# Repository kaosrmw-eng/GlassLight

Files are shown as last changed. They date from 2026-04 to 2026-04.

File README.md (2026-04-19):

# GlassLight

An open-source wearable smart light designed to clip onto Meta Rayban 2 glasses. Built on the Seeed Studio XIAO ESP32-C6 with a single WS2812B LED.

  

## Features

- **7-color palette** — cycle forward/back with physical buttons
- **WiFi config portal** — hold a button 3 seconds, connect your phone, configure everything
- **Live control page** — change color and brightness from your phone over WiFi
- **Persistent notepad** — up to 2MB of notes stored in SPIFFS, survives reboots
- **Battery monitoring** — ADC voltage divider, low/critical warnings via LED
- **Auto-off timer** — configurable idle shutoff
- **Light sleep** — drops to ~3mA idle when WiFi is off
- **3D printable enclosure** — STL files coming soon

## Hardware

| Component | Details |
|---|---|
| Board | Seeed Studio XIAO ESP32-C6 |
| LED | 1× WS2812B |
| Buttons | 3× tactile (next color, prev color, toggle/config) |
| Power | LiPo battery via XIAO onboard charger |

### Pin Map

| Signal | GPIO | XIAO Label |
|---|---|---|
| WS2812B Data | 18 | D10 |
| Button — Next Color | 20 | D9 |
| Button — Prev Color | 19 | D8 |
| Button — Toggle / Config | 17 | D7 |
| Battery ADC | 0 | D0 |

### Battery Sense Wiring

A resistor voltage divider brings the LiPo voltage into ADC range:

```
BAT+ ──[ 1kΩ ]──┬── D0 (GPIO0)
                │
             [100Ω]
                │
               GND
```

Divider ratio: 100 / (1000 + 100) = 0.0909  
LiPo full ~4.2V → ADC ~474 | LiPo empty ~3.0V → ADC ~339

> **Calibration:** Open Serial Monitor at 115200 baud and send `r` to read the raw ADC value. Update `BAT_ADC_FULL` and `BAT_ADC_EMPTY` in the firmware to match your actual readings.

## Button Reference

| Button | Action |
|---|---|
| D9 (Next) | Cycle to next active color |
| D8 (Prev) | Cycle to previous active color |
| D7 (Toggle) — tap | Turn LED on / off |
| D7 (Toggle) — hold 3s | Enter WiFi config mode (3× blue blink) |

## WiFi Config Mode

Connect to `GlassLight-Setup` (open network). The captive portal opens automatically on most phones.

| URL | Page |
|---|---|
| `192.168.4.1/` | Settings (boot color, brightness, auto-off, active colors) |
| `192.168.4.1/control` | Live LED control |
| `192.168.4.1/notes` | Persistent notepad (paste, edit, copy, clear) |

## Arduino Setup

### Library Required

Install via Arduino Library Manager:
- **Adafruit NeoPixel** by Adafruit

All other libraries (`WiFi`, `WebServer`, `DNSServer`, `Preferences`, `SPIFFS`) are included in the ESP32 Arduino core.

### Board Settings

| Setting | Value |
|---|---|
| Board | `XIAO_ESP32C6` (Tools → Board → ESP32 Arduino) |
| Partition Scheme | `Default 4MB with spiffs` ← **required for notepad** |

## Battery Warnings

| Level | Behavior |
|---|---|
| ≤ 20% | 3 red flashes every 60 seconds |
| ≤ 10% | Continuous slow red pulse (LED taken over) |

## 3D Enclosure

STL files for the glasses-clip enclosure coming soon.
Arch.stl - Connects both Batter & Esp32 enclosures and slides on left arm of the Meta RayBan 2 glasses.
Batt_LED_BoxA - Enclosre for battery and LED 
Batt_LED_BoxB - " lower half
Ctl_BoxA - Enclosure for Esp32 and buttons/switch
Ctl_BoxB - " lower half

## License

MIT — do whatever you want with it. Attribution appreciated but not required.

## Author

Rich Washburn — [richwashburn.com](https://richwashburn.com)

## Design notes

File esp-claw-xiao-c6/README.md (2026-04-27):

# ESP-Claw — XIAO ESP32-C6 Board Port

Board support files for running [ESP-Claw](https://github.com/espressif/esp-claw) on the **Seeed Studio XIAO ESP32-C6**.

## Hardware

| Item | Detail |
|---|---|
| Chip | ESP32-C6 (dual-core RISC-V, 160MHz HP + 20MHz LP) |
| Flash | 4MB |
| PSRAM | None |
| Wi-Fi | 6 (802.11ax) |
| BLE | 5.0 |
| Protocol | Zigbee / Thread / Matter |
| LED | WS2812 RGB on GPIO8 |

## Files

| File | Purpose |
|---|---|
| `board_info.yaml` | Chip target declaration (`esp32c6`) |
| `board_peripherals.yaml` | RMT config for GPIO8 WS2812 (no DMA — C6 limitation) |
| `board_devices.yaml` | LED strip device definition |
| `setup_device.c` | Board initialization stub |
| `sdkconfig.defaults.board` | C6-specific config: no SPIRAM, 4MB flash, trimmed buffers |
| `partitions_4MB_c6.csv` | Single OTA slot partition table for 4MB flash |

## Key Differences from S3 Reference Board

- **No PSRAM** — ESP-Claw's task allocator detects this at runtime and falls back to internal SRAM automatically. No code changes needed.
- **4MB Flash** — Single OTA slot (no OTA-1). 512K SPIFFS for emote + 512K FAT for skills/scripts.
- **RMT no DMA** — C6's RMT peripheral doesn't support DMA. `with_dma: false` in peripherals config.
- **GPIO8** — XIAO C6 onboard WS2812 is on GPIO8 (vs GPIO38 on S3 DevKitC).
- **160MHz CPU** — C6 max is 160MHz vs 240MHz on S3. Adequate for agent loop + Telegram IM.

## Build Instructions

### Prerequisites
- ESP-IDF v5.5.4+
- `pip install esp-bmgr-assist`

### Steps

```bash
# Clone ESP-Claw
git clone https://github.com/espressif/esp-claw.git
cd esp-claw/application/basic_demo

# Copy this board directory into boards/
cp -r /path/to/this/folder ./boards/xiao_esp32c6

# Copy partition table
cp /path/to/partitions_4MB_c6.csv ./

# Generate board config
idf.py gen-bmgr-config -c ./boards -b xiao_esp32c6

# Set IDF target
idf.py set-target esp32c6

# Configure (set WiFi, LLM key, Telegram token)
idf.py menuconfig

# Build + flash
idf.py build
idf.py flash monitor
```

## Recommended Configuration (menuconfig)

- **LLM**: Claude 3.5 Sonnet or DeepSeek V3 (strong tool-use, lower token cost)
- **IM**: Telegram (lightest, most reliable on constrained hardware)
- **Disable**: QQ, Feishu, WeChat (save RAM)
- **Memory module**: Optional — disable if RAM is tight
- **Web search**: Optional — enable if you have a Brave/Tavily key

## Status

- [ ] Build verified
- [ ] Flash verified  
- [ ] Telegram IM working
- [ ] Agent loop working
- [ ] MCP client working

*First attempt — community contributions welcome.*

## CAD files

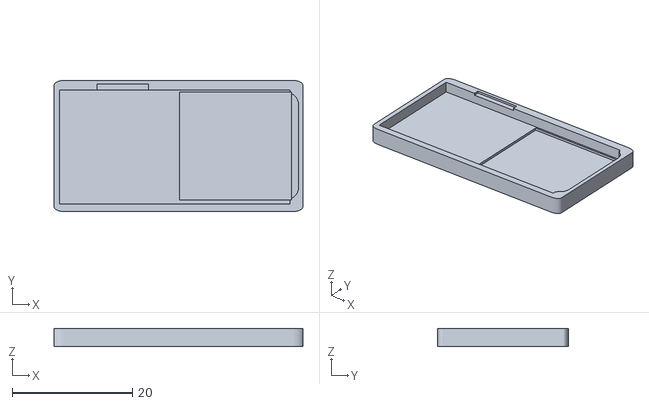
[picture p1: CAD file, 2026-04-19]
Ctl_boxB.stl
41.4 x 21.8 x 3.03

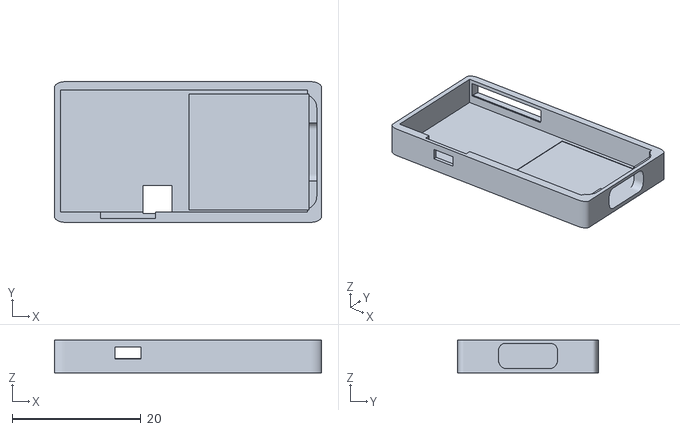
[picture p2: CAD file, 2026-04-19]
Ctl_boxA.stl
41.4 x 21.8 x 5.08

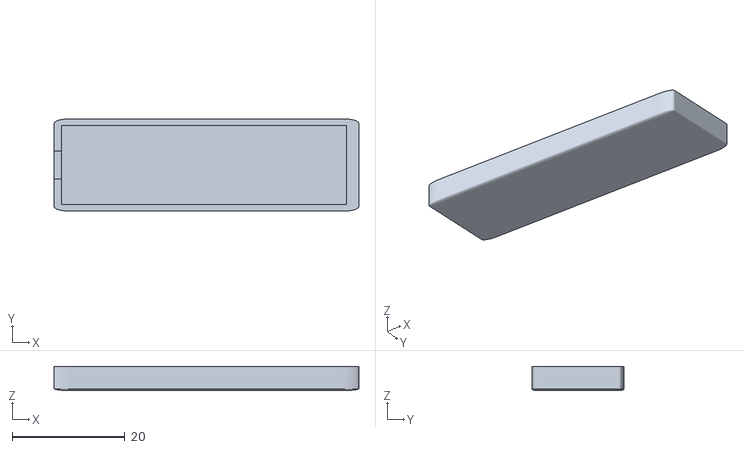
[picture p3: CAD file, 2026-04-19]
Batt_LED_boxA.stl
54.2 x 16.4 x 4.31

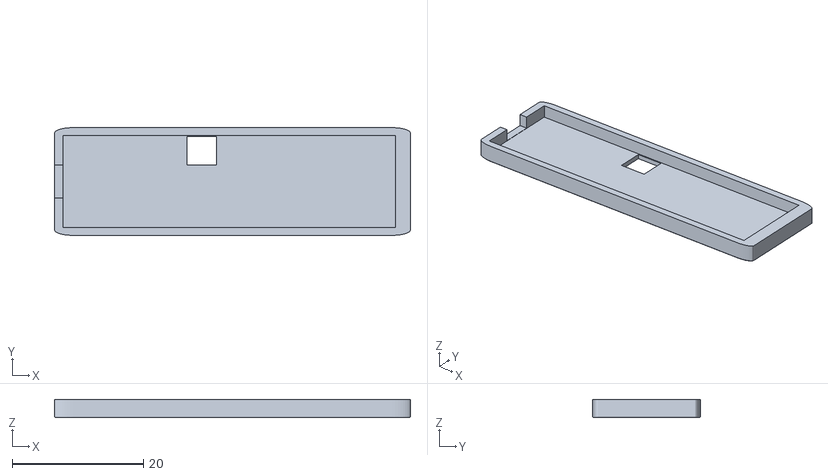
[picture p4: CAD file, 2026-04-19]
Batt_LED_boxB.stl
54.2 x 16.4 x 2.79

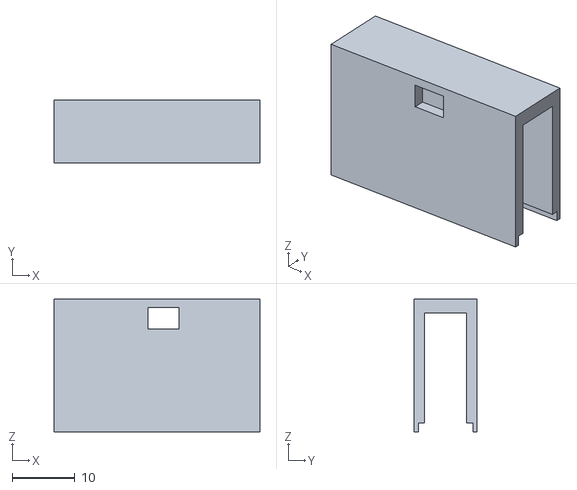
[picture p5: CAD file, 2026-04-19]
Arch.stl
32.9 x 10.1 x 21.2

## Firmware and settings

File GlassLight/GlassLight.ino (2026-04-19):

/*
 * ════════════════════════════════════════════════════════
 *  GlassLight v1.6
 *  Glasses-clip wearable smart light + notepad
 *  Seeed Studio XIAO ESP32-C6 + WS2812B
 * ════════════════════════════════════════════════════════
 *
 *  HARDWARE
 *  --------
 *  Board  : Seeed Studio XIAO ESP32-C6
 *  LED    : 1x WS2812B on D10 (GPIO18)
 *  Btn A  : D9  (GPIO20) -- Next color
 *  Btn B  : D8  (GPIO19) -- Previous color
 *  Btn C  : D7  (GPIO17) -- Tap: on/off | Hold 3s: WiFi config mode
 *  Power  : LiPo on BAT pins (XIAO onboard charger)
 *
 *  BATTERY SENSE WIRING
 *  ---------------------
 *    BAT+ --[ 1k ohm ]--+-- D0 (GPIO0, ADC)
 *                       |
 *                    [100 ohm]
 *                       |
 *                      GND
 *
 *  BATTERY CALIBRATION
 *  --------------------
 *  Send 'r' via Serial (115200) to print raw ADC.
 *  1. Unplug USB, fully charged  -> note raw -> set BAT_ADC_FULL
 *  2. Nearly dead                -> note raw -> set BAT_ADC_EMPTY
 *
 *  BUTTON REFERENCE
 *  -----------------
 *  Btn A (D9) : Tap       -> Next color
 *  Btn B (D8) : Tap       -> Previous color
 *  Btn C (D7) : Tap       -> Toggle LED on/off
 *             : Hold 3s   -> Enter WiFi config mode (3x blue blink, done)
 *
 *  WIFI CONFIG MODE
 *  -----------------
 *  SSID    : GlassLight-Setup  (open)
 *  Pages   :  /          Settings
 *             /control   Live LED control
 *             /notes     Persistent notepad
 *  Physical buttons work in config mode.
 *  No breathing animation -- LED stays off unless controlled.
 *
 *  NOTEPAD
 *  --------
 *  Stored in SPIFFS (/notes.txt). Survives reboots and reflashes.
 *  Max size: NOTE_MAX_BYTES. Paste prepends to top (newest first).
 *  Features: paste, copy, clear, character count, timestamps on entries.
 *
 *  POWER
 *  ------
 *  WiFi off: light sleep between ticks (~3mA idle)
 *  WiFi on : full active (~30mA + LED)
 *
 *  BATTERY WARNINGS
 *  -----------------
 *  <= 20% : 3 red flashes every 60s
 *  <= 10% : Continuous slow red pulse
 *
 *  LIBRARY REQUIRED
 *  -----------------
 *  Adafruit NeoPixel  (Arduino Library Manager)
 *
 *  BOARD SETTINGS
 *  ---------------
 *  Board     : XIAO_ESP32C6
 *  Partition : Default 4MB with spiffs  <-- IMPORTANT for notepad storage
 * ════════════════════════════════════════════════════════
 */

#include <Adafruit_NeoPixel.h>
#include <WiFi.h>
#include <WebServer.h>
#include <DNSServer.h>
#include <Preferences.h>
#include <SPIFFS.h>
#include "esp_sleep.h"

// ─────────────────────────────────────────
//  PINS
// ─────────────────────────────────────────
#define LED_PIN       18
#define BTN_NEXT      20
#define BTN_PREV      19
#define BTN_TOGGLE    17
#define BAT_ADC_PIN    0

// ─────────────────────────────────────────
//  DEFAULTS
// ─────────────────────────────────────────
#define DEFAULT_COLOR_INDEX   0
#define DEFAULT_BRIGHTNESS    191
#define DEFAULT_AUTO_OFF      0

// ─────────────────────────────────────────
//  TIMING
// ─────────────────────────────────────────
#define CONFIG_HOLD_MS        3000
#define DEBOUNCE_MS           50
#define LIGHT_SLEEP_US        20000

// ─────────────────────────────────────────
//  WIFI
// ─────────────────────────────────────────
#define AP_SSID               "GlassLight-Setup"
#define AP_PASS               ""
#define DNS_PORT              53
#define HTTP_PORT             80

// ─────────────────────────────────────────
//  BATTERY
// ─────────────────────────────────────────
#define BAT_LOW_PCT           20
#define BAT_CRITICAL_PCT      10
#define BAT_CHECK_INTERVAL    30000
#define BAT_WARN_INTERVAL     60000
#define BAT_ADC_FULL          390    // calibrate: send 'r' via serial
#define BAT_ADC_EMPTY         280

// ─────────────────────────────────────────
//  NOTEPAD
// ─────────────────────────────────────────
#define NOTES_FILE            "/notes.txt"
#define NOTE_MAX_BYTES        2097152  // 2MB max notepad size
#define NOTE_ENTRY_SEPARATOR  "\n---\n"

// ─────────────────────────────────────────
//  BRAND
// ─────────────────────────────────────────
#define BRAND_RED  "#B71723"

// ─────────────────────────────────────────
//  COLOR PALETTE
// ─────────────────────────────────────────
struct Color { const char* name; uint8_t r, g, b; };
Color palette[] = {
  { "White",      255, 255, 255 },
  { "Warm White", 255, 180,  80 },
  { "Red",        255,   0,   0 },
  { "Blue",         0,   0, 255 },
  { "Green",        0, 255,   0 },
  { "Purple",     180,   0, 255 },
  { "Cyan",         0, 255, 255 },
};
#define NUM_COLORS (sizeof(palette) / sizeof(palette[0]))
uint8_t activeColors = 0x7F;

// ─────────────────────────────────────────
//  GLOBALS
// ─────────────────────────────────────────
Adafruit_NeoPixel led(1, LED_PIN, NEO_GRB + NEO_KHZ800);
Preferences       prefs;
WebServer         server(HTTP_PORT);
DNSServer         dns;

int           colorIndex    = DEFAULT_COLOR_INDEX;
uint8_t       brightness    = DEFAULT_BRIGHTNESS;
int           autoOffMin    = DEFAULT_AUTO_OFF;
bool          ledOn         = true;
bool          configMode    = false;
unsigned long ledOnTime     = 0;

unsigned long togglePressAt   = 0;
bool          toggleHeld      = false;
unsigned long lastNextPress   = 0;
unsigned long lastPrevPress   = 0;
unsigned long lastTogglePress = 0;
bool          prevNextState   = HIGH;
bool          prevPrevState   = HIGH;
bool          prevToggleState = HIGH;

int           batPercent    = 100;
bool          batLow        = false;
bool          batCritical   = false;
unsigned long lastBatCheck  = 0;
unsigned long lastBatWarn   = 0;

// ═════════════════════════════════════════
//  BATTERY
// ═════════════════════════════════════════

int readBatteryPercent() {
  long sum = 0;
  for (int i = 0; i < 16; i++) { sum += analogRead(BAT_ADC_PIN); delay(2); }
  int raw = (int)(sum / 16);
  int pct = (int)map(raw, BAT_ADC_EMPTY, BAT_ADC_FULL, 0, 100);
  pct = constrain(pct, 0, 100);
  Serial.printf("[BAT] ADC raw: %d  ->  %d%%\n", raw, pct);
  return pct;
}

void printRawADC() {
  long sum = 0;
  for (int i = 0; i < 16; i++) { sum += analogRead(BAT_ADC_PIN); delay(2); }
  Serial.printf("[CAL] Raw ADC: %d  (FULL=%d EMPTY=%d)\n",
    (int)(sum/16), BAT_ADC_FULL, BAT_ADC_EMPTY);
}

void checkBattery() {
  if (millis() - lastBatCheck < BAT_CHECK_INTERVAL) return;
  lastBatCheck = millis();
  batPercent  = readBatteryPercent();
  batCritical = (batPercent <= BAT_CRITICAL_PCT);
  batLow      = (batPercent <= BAT_LOW_PCT);
}

void flashBatWarning(int times) {
  uint32_t saved = led.getPixelColor(0);
  for (int i = 0; i < times; i++) {
    led.setPixelColor(0, led.Color(255,0,0)); led.show(); delay(150);
    led.setPixelColor(0, 0);                  led.show(); delay(150);
  }
  led.setPixelColor(0, saved); led.show();
}

void handleBatteryWarning() {
  unsigned long now = millis();
  if (batCritical) {
    static uint8_t pulse = 0; static int8_t pdir = 1;
    static unsigned long lastPulse = 0;
    if (now - lastPulse > 20) {
      lastPulse = now;
      pulse = (uint8_t)constrain((int)pulse + pdir*4, 4, 180);
      if (pulse >= 180) pdir = -1;
      if (pulse <=   4) pdir =  1;
      led.setPixelColor(0, led.Color(pulse,0,0)); led.show();
    }
    return;
  }
  if (batLow && (now - lastBatWarn > BAT_WARN_INTERVAL)) {
    lastBatWarn = now;
    flashBatWarning(3);
  }
}

// ═════════════════════════════════════════
//  LED HELPERS
// ═════════════════════════════════════════

void applyLED() {
  if (!ledOn) { led.setPixelColor(0,0); led.show(); return; }
  Color& c = palette[colorIndex];
  led.setPixelColor(0, led.Color(
    (c.r*brightness)/255, (c.g*brightness)/255, (c.b*brightness)/255));
  led.show();
}

int nextActiveColor(int current, int dir) {
  for (int i = 1; i <= (int)NUM_COLORS; i++) {
    int idx = ((current + dir*i) % (int)NUM_COLORS + NUM_COLORS) % NUM_COLORS;
    if (activeColors & (1<<idx)) return idx;
  }
  return current;
}

void blinkLED(uint8_t r, uint8_t g, uint8_t b, int times, int ms) {
  for (int i = 0; i < times; i++) {
    led.setPixelColor(0, led.Color(r,g,b)); led.show(); delay(ms);
    led.setPixelColor(0, 0);               led.show(); delay(ms);
  }
}

// ═════════════════════════════════════════
//  PREFERENCES
// ═════════════════════════════════════════

void loadPrefs() {
  prefs.begin("glasslight", true);
  colorIndex   = prefs.getInt("color",    DEFAULT_COLOR_INDEX);
  brightness   = prefs.getUChar("bright", DEFAULT_BRIGHTNESS);
  autoOffMin   = prefs.getInt("autooff",  DEFAULT_AUTO_OFF);
  activeColors = prefs.getUChar("active", 0x7F);
  prefs.end();
  if (colorIndex < 0 || colorIndex >= (int)NUM_COLORS) colorIndex = 0;
  if (brightness < 12) brightness = DEFAULT_BRIGHTNESS;
  if (activeColors == 0) activeColors = 0x7F;
  if (!(activeColors & (1<<colorIndex))) colorIndex = nextActiveColor(colorIndex, 1);
}

void savePrefs() {
  prefs.begin("glasslight", false);
  prefs.putInt("color",    colorIndex);
  prefs.putUChar("bright", brightness);
  prefs.putInt("autooff",  autoOffMin);
  prefs.putUChar("active", activeColors);
  prefs.end();
}

// ═════════════════════════════════════════
//  NOTEPAD  (SPIFFS)
// ═════════════════════════════════════════

// Get file size without loading into RAM
size_t notesSize() {
  if (!SPIFFS.exists(NOTES_FILE)) return 0;
  File f = SPIFFS.open(NOTES_FILE, "r");
  if (!f) return 0;
  size_t sz = f.size();
  f.close();
  return sz;
}

// Prepend new entry using a temp file — never loads full content into RAM
void prependNote(const String& entry) {
  if (entry.length() == 0) return;
  String header = entry + NOTE_ENTRY_SEPARATOR;

  // Check if adding this would exceed limit; if so, we'll truncate from the end
  size_t existingSize = notesSize();
  size_t newTotal     = header.length() + existingSize;
  size_t writeLimit   = (newTotal > NOTE_MAX_BYTES) ? NOTE_MAX_BYTES : newTotal;

  // Write to temp file: header first, then existing content up to limit
  File tmp = SPIFFS.open("/notes_tmp.txt", "w");
  if (!tmp) { Serial.println("[NOTES] Temp write failed"); return; }

  size_t written = 0;

  // Write header
  for (int i = 0; i < (int)header.length() && written < writeLimit; i++) {
    tmp.write((uint8_t)header[i]);
    written++;
  }

  // Stream existing file
  if (written < writeLimit && SPIFFS.exists(NOTES_FILE)) {
    File old = SPIFFS.open(NOTES_FILE, "r");
    if (old) {
      uint8_t buf[256];
      while (old.available() && written < writeLimit) {
        size_t toRead = min((size_t)256, writeLimit - written);
        size_t got    = old.read(buf, toRead);
        tmp.write(buf, got);
        written += got;
      }
      old.close();
    }
  }
  tmp.close();

  // Replace notes file with temp
  SPIFFS.remove(NOTES_FILE);
  SPIFFS.rename("/notes_tmp.txt", NOTES_FILE);
  Serial.printf("[NOTES] Saved %d bytes\n", written);
}

void clearNotes() {
  SPIFFS.remove(NOTES_FILE);
  Serial.println("[NOTES] Cleared");
}

// HTML-escape for safe display in textarea
String htmlEscape(String s) {
  s.replace("&",  "&amp;");
  s.replace("<",  "&lt;");
  s.replace(">",  "&gt;");
  s.replace("\"", "&quot;");
  return s;
}

// ═════════════════════════════════════════
//  HTML SHELL
// ═════════════════════════════════════════

String htmlHead(const char* title) {
  return String(F("<!DOCTYPE html><html><head>"
    "<meta charset='UTF-8'>"
    "<meta name='viewport' content='width=device-width,initial-scale=1'>"
    "<title>")) + title + F("</title>"
    "<style>"
    "body{font-family:sans-serif;background:#111;color:#eee;"
         "max-width:440px;margin:0 auto;padding:20px}"
    "h1{color:" BRAND_RED ";font-size:1.5em;margin-bottom:2px}"
    "nav{margin-bottom:18px;border-bottom:1px solid #2a2a2a;padding-bottom:10px}"
    "nav a{color:#666;text-decoration:none;margin-right:16px;font-size:.88em;"
           "padding:4px 0;border-bottom:2px solid transparent;transition:color .2s}"
    "nav a.active{color:" BRAND_RED ";border-bottom:2px solid " BRAND_RED "}"
    "nav a:hover{color:#ccc}"
    ".sub{color:#444;font-size:.76em;margin:0 0 8px}"
    ".bat{font-size:.8em;padding:4px 9px;border-radius:5px;"
         "display:inline-block;margin-bottom:14px}"
    ".bat-ok{background:#1a3a1a;color:#00ff99}"
    ".bat-low{background:#3a2a00;color:#ffaa00}"
    ".bat-crit{background:#3a0000;color:#ff5555}"
    "label{display:block;margin-top:16px;font-size:.86em;color:#aaa}"
    "select,input[type=range],input[type=number]{"
      "width:100%;margin-top:5px;padding:8px;background:#1a1a1a;"
      "border:1px solid #2e2e2e;color:#eee;border-radius:6px;"
      "font-size:1em;box-sizing:border-box}"
    ".val{color:" BRAND_RED ";font-weight:bold}"
    ".chips{display:flex;flex-wrap:wrap;gap:7px;margin-top:8px}"
    ".chip{display:flex;align-items:center;gap:5px;background:#1a1a1a;"
      "border:1px solid #2e2e2e;border-radius:6px;padding:6px 9px;"
      "font-size:.83em;cursor:pointer}"
    ".chip input{width:14px;height:14px}"
    ".sw{width:12px;height:12px;border-radius:50%;border:1px solid #444;flex-shrink:0}"
    // Buttons
    ".btn-red{display:block;width:100%;padding:13px;background:" BRAND_RED ";"
      "color:#fff;border:none;border-radius:8px;font-size:.95em;font-weight:bold;"
      "cursor:pointer;text-align:center;text-decoration:none;box-sizing:border-box;margin-top:20px}"
    ".btn-red:active{background:#8a1118}"
    ".btn-dark{display:block;width:100%;padding:11px;background:#1e1e1e;"
      "color:#eee;border:1px solid #333;border-radius:8px;font-size:.9em;"
      "cursor:pointer;text-align:center;box-sizing:border-box;margin-top:10px}"
    ".btn-dark:active{background:#2a2a2a}"
    ".ctrl-grid{display:grid;grid-template-columns:1fr 1fr;gap:9px;margin-top:14px}"
    ".ctrl-btn{padding:14px 6px;background:#1a1a1a;border:1px solid #2e2e2e;"
      "border-radius:8px;color:#eee;font-size:.88em;cursor:pointer;width:100%;margin:0}"
    ".ctrl-btn:active{background:#262626}"
    ".active-color{border-color:" BRAND_RED " !important;color:" BRAND_RED " !important}"
    ".color-bar{height:5px;border-radius:3px;margin-top:7px}"
    ".big-toggle{font-size:1.3em;padding:16px}"
    ".row{display:flex;gap:9px;margin-top:12px}"
    ".row form{flex:1;margin:0}"
    // Notepad
    "textarea{width:100%;background:#0d0d0d;color:#ddd;border:1px solid #2e2e2e;"
      "border-radius:8px;padding:12px;font-size:.88em;font-family:monospace;"
      "resize:vertical;box-sizing:border-box;min-height:260px;line-height:1.5}"
    ".note-toolbar{display:flex;gap:8px;margin-top:12px}"
    ".note-toolbar form{flex:1;margin:0}"
    ".note-meta{font-size:.75em;color:#444;margin-top:6px;text-align:right}"
    ".toast{display:none;background:#1a3a1a;color:#00ff99;padding:8px 12px;"
      "border-radius:6px;font-size:.82em;margin-top:8px;text-align:center}"
    "</style>");
}

String batBadge() {
  String cls, lbl;
  if      (batCritical) { cls="bat-crit"; lbl="Battery: CRITICAL " +String(batPercent)+"%"; }
  else if (batLow)      { cls="bat-low";  lbl="Battery: Low "      +String(batPercent)+"%"; }
  else                  { cls="bat-ok";   lbl="Battery: "          +String(batPercent)+"%"; }
  return "<div class='bat "+cls+"'>"+lbl+"</div>";
}

String navBar(const char* active) {
  String s = "<nav>";
  s += String("<a href='/'")         + (strcmp(active,"settings")==0 ? " class='active'" : "") + ">Settings</a>";
  s += String("<a href='/control'")  + (strcmp(active,"control") ==0 ? " class='active'" : "") + ">Control</a>";
  s += String("<a href='/notes'")    + (strcmp(active,"notes")   ==0 ? " class='active'" : "") + ">Notepad</a>";
  s += "</nav>";
  return s;
}

// ═════════════════════════════════════════
//  SETTINGS PAGE
// ═════════════════════════════════════════

String buildSettingsPage() {
  String html = htmlHead("GlassLight");
  html += F("</head><body>");
  html += F("<h1>GlassLight</h1><p class='sub'>v1.6 &mdash; wearable config</p>");
  html += navBar("settings");
  html += batBadge();
  html += F("<form method='POST' action='/save'>");

  html += F("<label>Boot Color</label><select name='color'>");
  for (int i = 0; i < (int)NUM_COLORS; i++) {
    html += "<option value='"+String(i)+"'";
    if (i==colorIndex) html += " selected";
    html += ">"+String(palette[i].name)+"</option>";
  }
  html += F("</select>");

  int bpct = (brightness*100)/255;
  html += F("<label>Boot Brightness: <span class='val' id='bv'>");
  html += String(bpct);
  html += F("%</span></label><input type='range' name='brightness' min='5' max='100' value='");
  html += String(bpct);
  html += F("' oninput=\"document.getElementById('bv').textContent=this.value+'%'\">");

  html += F("<label>Auto-Off (minutes &mdash; 0 = stay on)</label>"
            "<input type='number' name='autooff' min='0' max='999' value='");
  html += String(autoOffMin);
  html += F("'>");

  html += F("<label>Colors Active in Cycle</label><div class='chips'>");
  const char* sw[] = {"#fff","#ffb450","#f00","#00f","#0f0","#b400ff","#0ff"};
  for (int i = 0; i < (int)NUM_COLORS; i++) {
    html += "<label class='chip'><input type='checkbox' name='c"+String(i)+"'";
    if (activeColors & (1<<i)) html += " checked";
    html += "><div class='sw' style='background:"+String(sw[i])+"'></div>";
    html += String(palette[i].name)+"</label>";
  }
  html += F("</div>");
  html += F("<button class='btn-red' type='submit'>Save &amp; Restart</button>");
  html += F("</form></body></html>");
  return html;
}

// ═════════════════════════════════════════
//  CONTROL PAGE
// ═════════════════════════════════════════

String buildControlPage() {
  String html = htmlHead("GlassLight Control");
  html += F("</head><body>");
  html += F("<h1>GlassLight</h1><p class='sub'>v1.6 &mdash; live control</p>");
  html += navBar("control");
  html += batBadge();

  html += F("<form method='POST' action='/ctrl'>"
    "<input type='hidden' name='action' value='toggle'>"
    "<button class='btn-red big-toggle' type='submit'>");
  html += ledOn ? "Turn OFF" : "Turn ON";
  html += F("</button></form>");

  html += F("<label style='margin-top:18px'>Color</label><div class='ctrl-grid'>");
  const char* sw[] = {"#fff","#ffb450","#f00","#00f","#0f0","#b400ff","#0ff"};
  for (int i = 0; i < (int)NUM_COLORS; i++) {
    if (!(activeColors & (1<<i))) continue;
    bool cur = (i==colorIndex && ledOn);
    html += "<form method='POST' action='/ctrl' style='margin:0'>"
            "<input type='hidden' name='action' value='color'>"
            "<input type='hidden' name='idx' value='"+String(i)+"'>"
            "<button type='submit' class='ctrl-btn"+(cur?" active-color":"")+"'>"
            "<div class='color-bar' style='background:"+String(sw[i])+"'></div>"
            +String(palette[i].name)+"</button></form>";
  }
  html += F("</div>");

  int bpct = (brightness*100)/255;
  html += F("<form method='POST' action='/ctrl'>"
    "<input type='hidden' name='action' value='bright'>"
    "<label>Brightness: <span class='val' id='bv'>");
  html += String(bpct);
  html += F("%</span></label><input type='range' name='brightness' min='5' max='100' value='");
  html += String(bpct);
  html += F("' oninput=\"document.getElementById('bv').textContent=this.value+'%'\">"
    "<button class='btn-red' type='submit'>Set Brightness</button></form>");

  html += F("<div class='row'>"
    "<form method='POST' action='/ctrl'><input type='hidden' name='action' value='prev'>"
    "<button type='submit' class='ctrl-btn'>&#9664; Prev</button></form>"
    "<form method='POST' action='/ctrl'><input type='hidden' name='action' value='next'>"
    "<button type='submit' class='ctrl-btn'>Next &#9654;</button></form></div>");

  html += F("</body></html>");
  return html;
}

// ═════════════════════════════════════════
//  NOTEPAD PAGE
// ═════════════════════════════════════════
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
void loop() {
  if (Serial.available()) {
    char c = Serial.read();
    if (c=='r'||c=='R') printRawADC();
  }

  if (configMode) {
    runConfigMode();
    handleButtons();
    checkAutoOff();
    return;
  }

  handleButtons();
  checkAutoOff();
  checkBattery();
  if (batCritical || batLow) handleBatteryWarning();

  esp_sleep_enable_timer_wakeup(LIGHT_SLEEP_US);
  esp_light_sleep_start();
}
